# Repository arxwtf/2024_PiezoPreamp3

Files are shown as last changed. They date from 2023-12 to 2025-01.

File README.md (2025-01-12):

# Piezo Preamp with Baxandall Tone Control and Battery Indicator

A simple preamp to be used for e.g. guitar piezo (contact) microphones. 

Created in KiCAD v8 and LTSpice.

### [**User manual**](Arx_PiezoPreamp-User_Manual.pdf) | [**Detailed info**](https://arx.wtf/blog/3-piezo-preamp) | [**Enclosure**](https://github.com/arxwtf/2024_PiezoPreamp3_Enclosure)

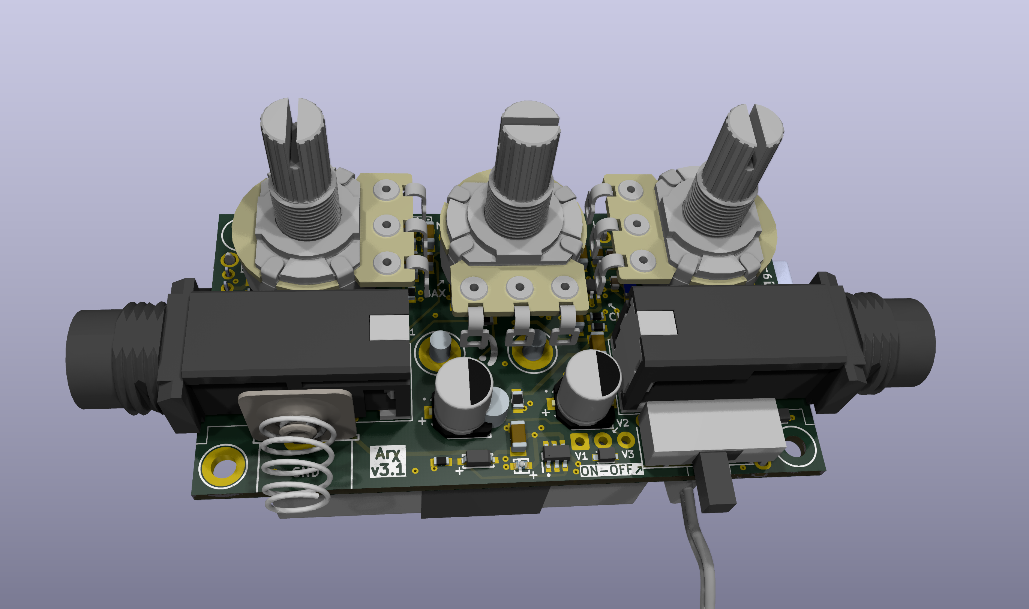
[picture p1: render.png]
Rendered PCB


## Main circuit blocks

### Charge amplifier for piezo 

Basically an integrator circuit. Provides low-impedance input. The gain is adjustable and depends on the input piezo capacitance. In my measurements, piezo discs have following capacitances:

- small disc (15mm diameter): ~7-10nF
- medium disc (27mm diameter): ~16-22nF
- large disc (35mm diameter): ~37-40nF

But I've also seen mentions of piezo discs with <10nF capacitance. Connecting multiple piezo discs in parallel increases the capacitance, so the maximum piezo capacitance can be in order of ~100nF or so.

The gain of the charge amp is then set by the ration of piezo capacitance to charge amp feedback capacitance. The **gain slide switch** is used to select from these feedback capacitances:

- 1nF
- 5.7nF
- 10.4nF
- 23nF

Input is protected by ESD bidirectional diode.

OPA145 is the opamp of choice because of these characteristics:
- JFET input stage, which means low input bias and offset current - critical for a charge amplifier
- low quiescent current (0.7mA max) for battery operation
- acceptable input voltage noise density (7nV/rtHz)
- good current noise density (0.8fA/rtHz)
- sufficient slew rate for audio (20V/us)
- sufficient GBW (5.5MHz)
- single supply voltage range 4.5V - 36V
- output voltage swing (V- +0.3, V+ -0.3)

Opamp also unfortunately seems to have bias current cancellation, which might introduce more current noise - this has to be determined by measurement. The same opamp is also used for Baxandall tone control section. Two single OPA145 components are used instead of dual OPA2145 package because it's easier to route, minimizes crosstalk and improves power dissipation (less heat). This increases the price, of course.

### High-pass filter with HPF switch

The charge amp is followed by a simple first-order high-pass filter with switchable cutoff frequency:
- 0Hz 
- 50Hz
- 77Hz
- 113Hz

The cutoff frequency is selectable by **HPF slide switch**.

### Baxandall tone control with Center switch

Bass and treble can be adjusted independently by **Bass pot** and **Treble pot** in the ranges of +-10dB. The center frequency is switchable by **Center slide switch**:

- 350Hz
- 600Hz
- 1kHz

Output audio is routed through **Volume pot** and protected by ESD bidirectional diode.

### Power-on LED and battery indicator
The power-on LED can work in two modes, switchable by LED mode switch:
- always on (switch left)
- "battery indication mode" (switch right)

**Battery indication mode (BI)** causes the LED to flash briefly when the circuit is switched on (by inserting mono plug to output jack + moving the power-on switch to the right). The longer the flash, the lower the battery voltage (remaining capacity). Under certain threshold, the LED will stay on permanentnly, signalling the need for replacement. This **BI threshold** is adjustable by on-board trimmer pot and needs to be determined by voltmeter measurement.

### Power supply
Designed for 9V batteries or DC pedal power supplies, but should theoretically be able to work properly with up to 18V DC.

Power enters the PCB by means of standardi 5.5/2.1mm DC IN connector with switch to disconnect internal 9V battery.

Contains ESD protection (bidirectional diode), MOSFET reverse polarity protection (with Zener gate protection and CLR) and input pi filter.

### OFF/ON switch with true bypass
The power-on switch works as a true bypass switch in its left position. The device is switched on by moving the switch to the right and insertin a **mono** male audio plug into the output jack.

## Simulation: /ltspice folder
LTSpice simulations (transient, AC, noise, stability) and some graphs are available in `ltspice/` folder.

## /library folder
Folder containing all 3rd symbols, footprints and 3D models used in the project. Other than that, only standard KiCAD symbols are used (opamps, ).

## /production folder
Contains gerbers, position files, BOM file, screenshot of JLC settings etc.

## /resources folder
Contains some additional resources, inspiration and schematics used during development.

## /schematics folder
Contains schematic sheets plotted from KiCAD, individually as .png and in one file as .pdf.

## Known problems
- when the circuit is turned ON or OFF (by the power-on switch and inserting of cable into AUDIO OUT jack), it might produce a strong voltage transient (a loud "pop"). Be careful when you're using it with sensitive equipment downstream.

- battery spring (used only for grounding) is too close to the PCB edge. This creates unnecessary force between the PCB and the enclosure wall. The spring can be shortened, or not used at all.

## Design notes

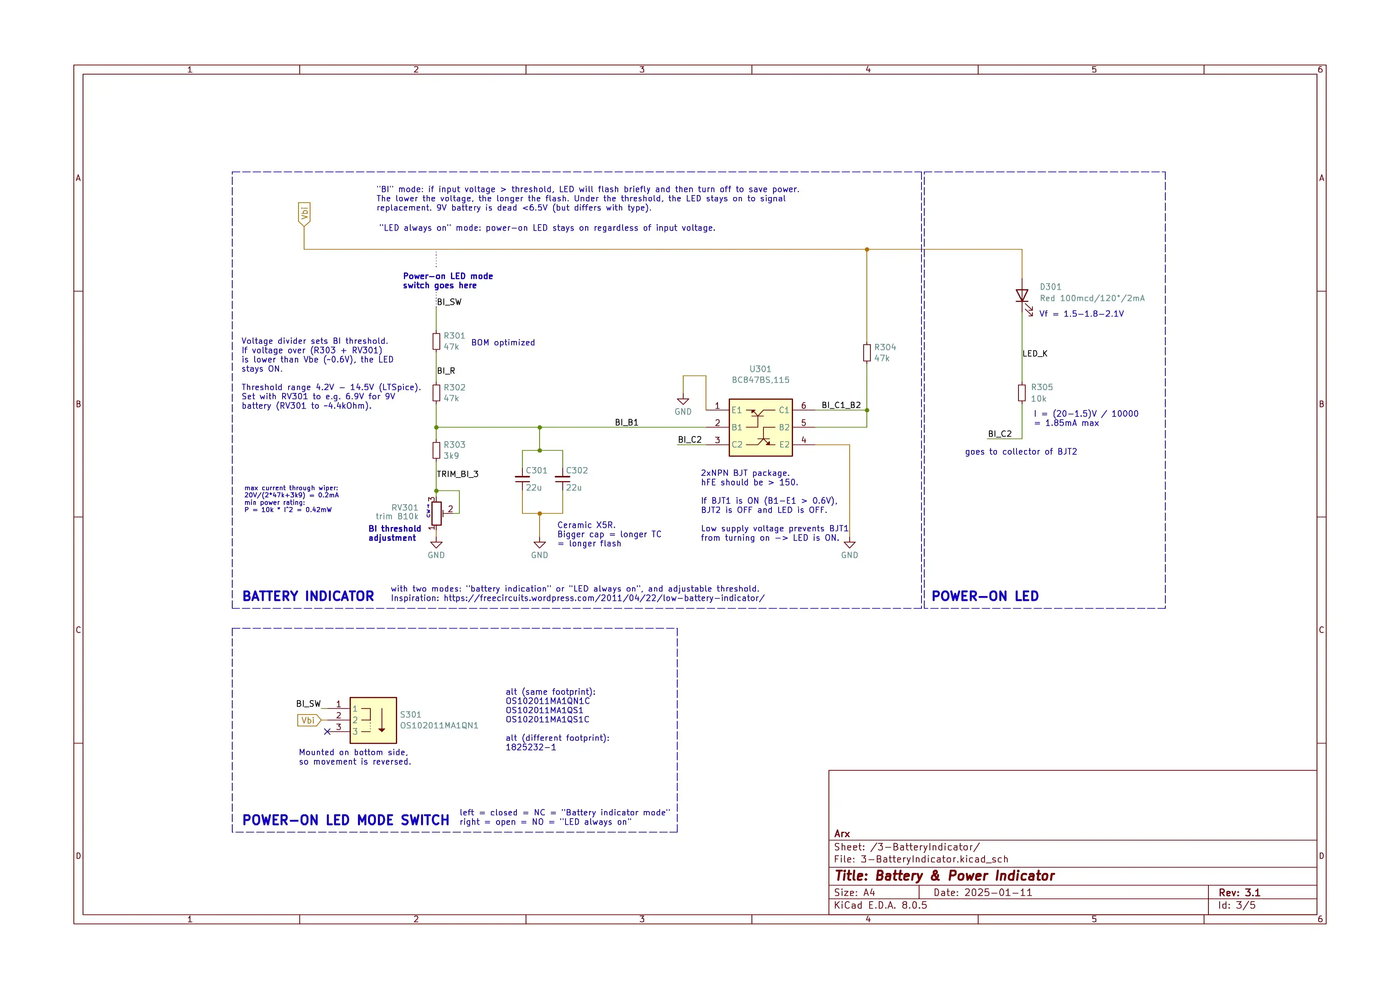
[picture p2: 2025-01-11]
schematics/3-BatteryIndicator.webp

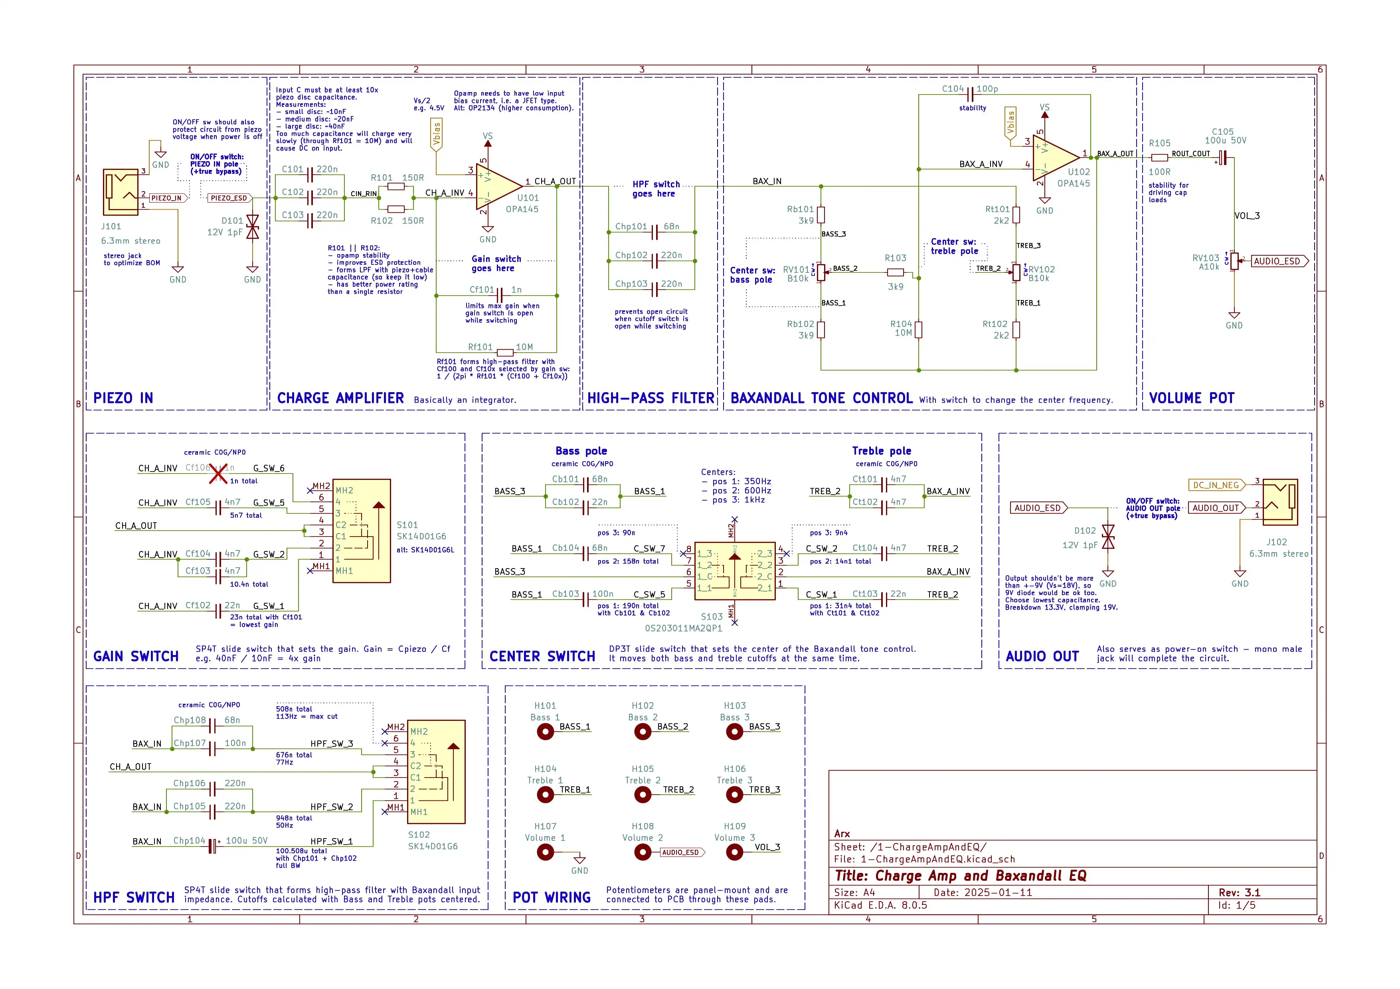
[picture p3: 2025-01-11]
schematics/1-ChargeAmpAndEQ.webp

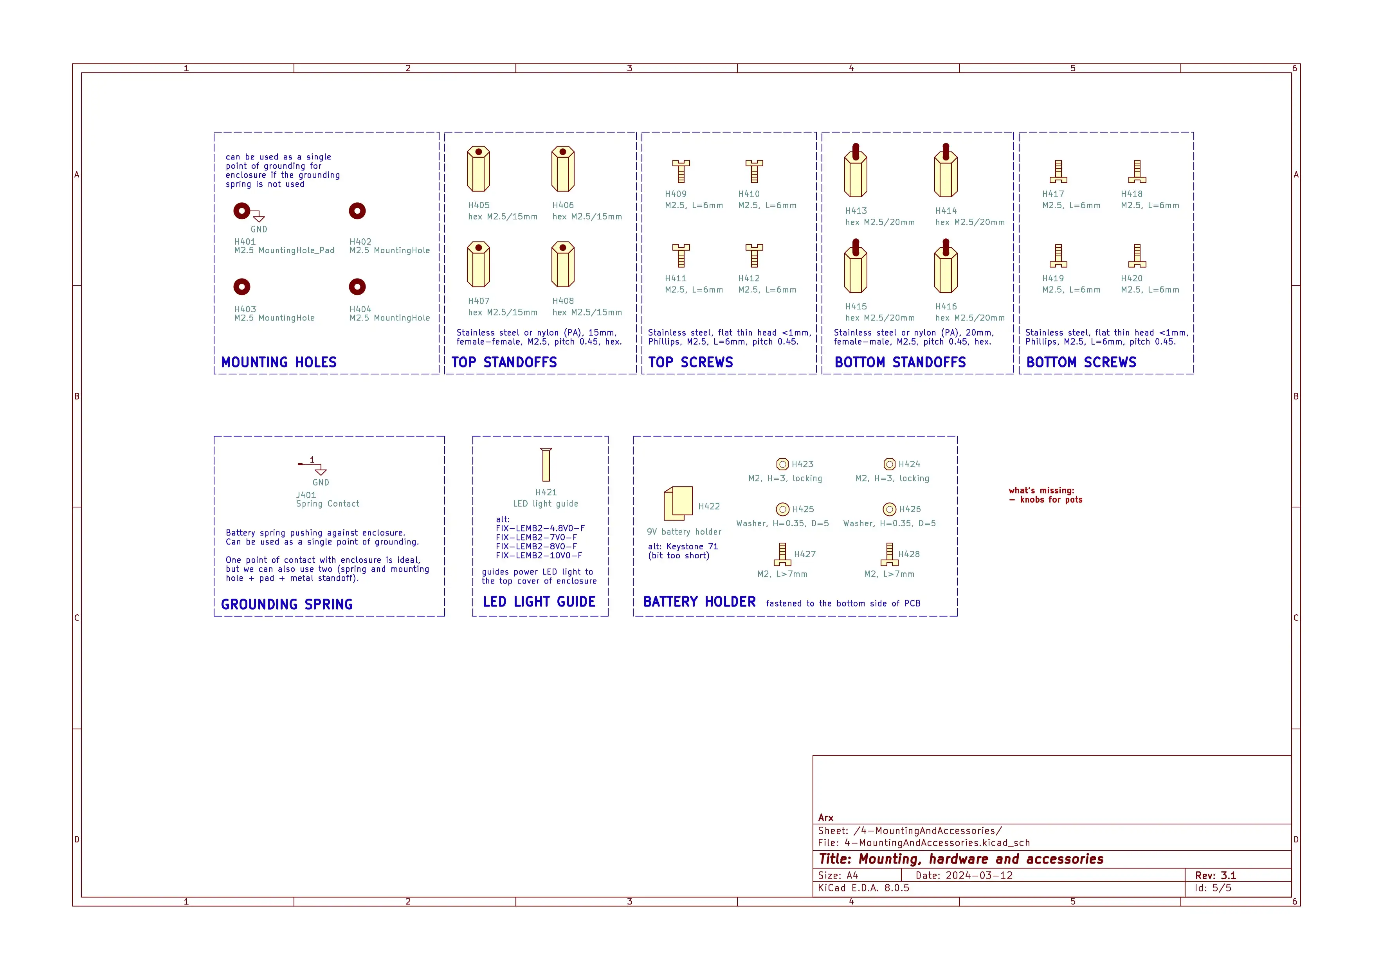
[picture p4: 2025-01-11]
schematics/4-MountingAndAccessories.webp

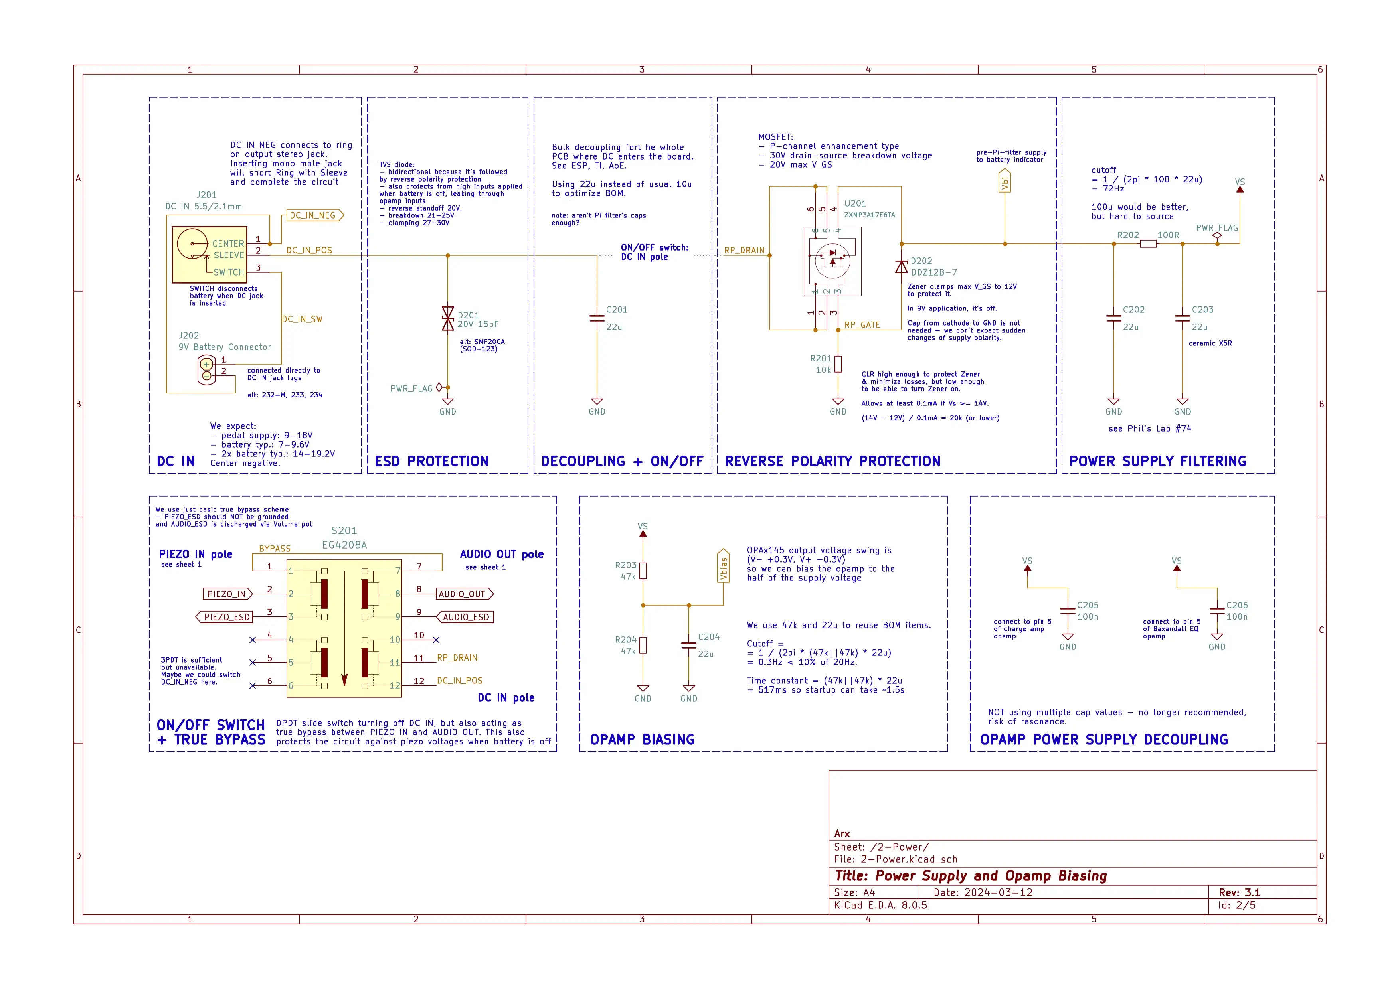
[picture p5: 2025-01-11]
schematics/2-Power.webp

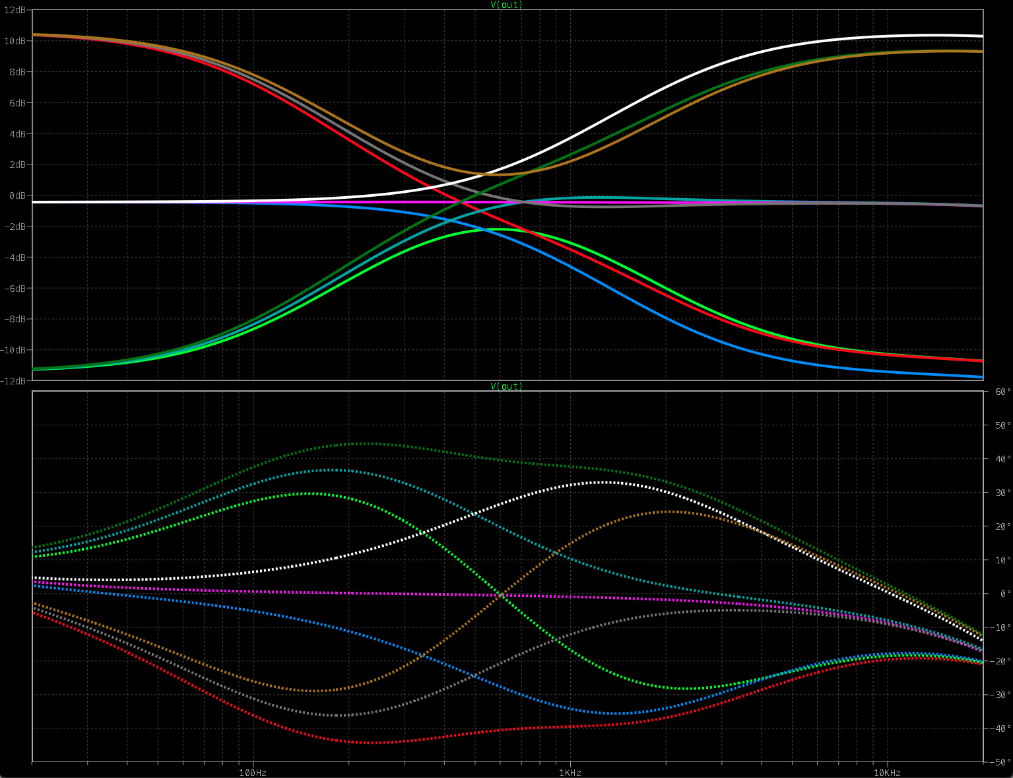
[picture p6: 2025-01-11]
ltspice/simulation-charge_amp+bax_600Hz.png

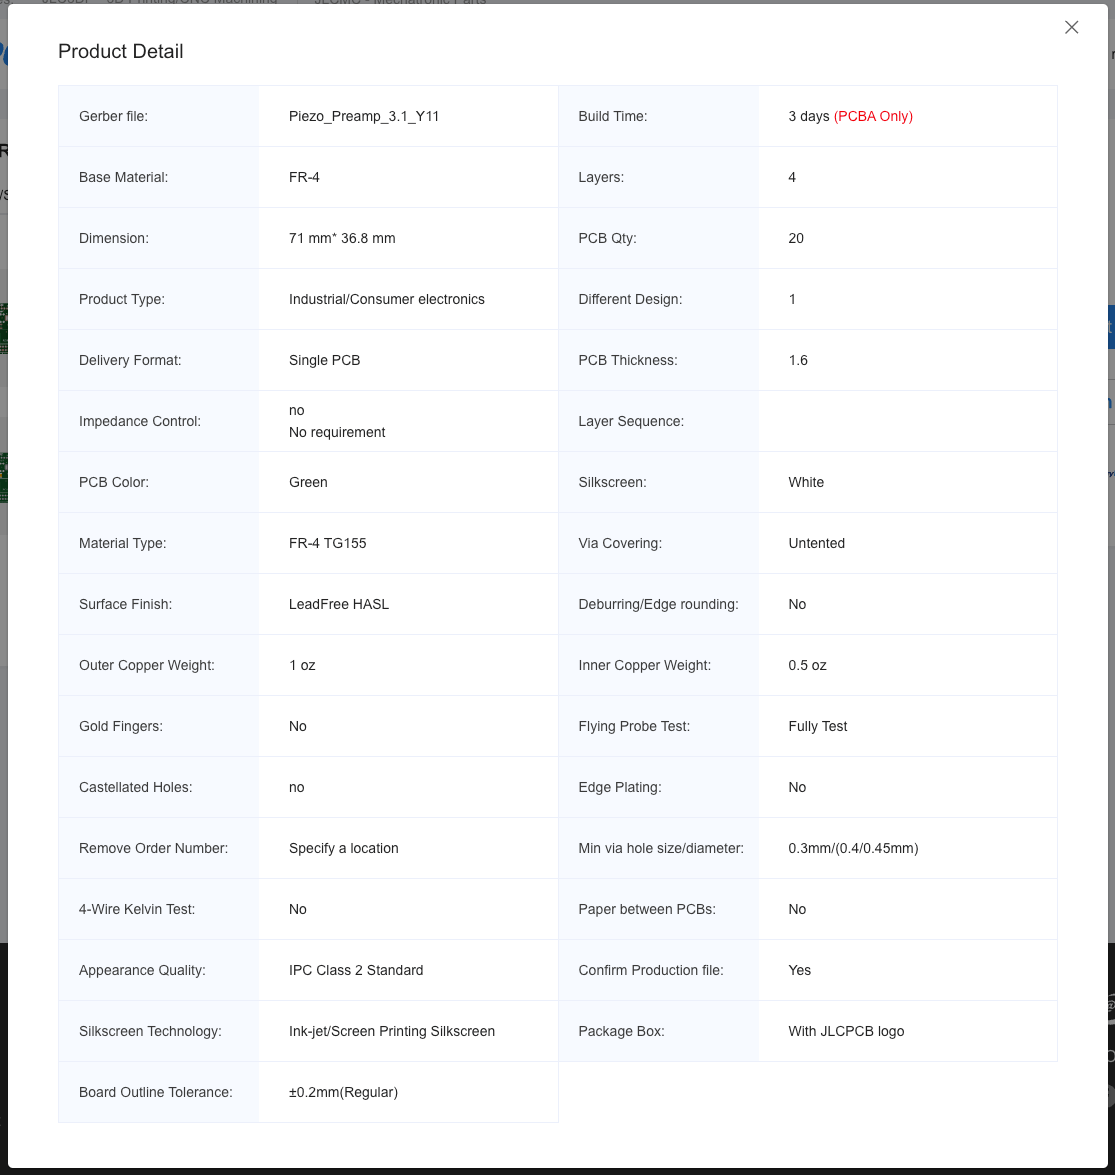
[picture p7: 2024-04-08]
production/settings/JLCPCB-Fab_settings_v3_1.png

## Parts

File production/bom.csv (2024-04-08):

Designator | Footprint | Quantity | Value | LCSC Part #
C101, C102, C103, Chp102, Chp103, Chp105, Chp106 | GRM31C5C1H224JE02L | 7 | 220n | C464977
C104 | cap_CL10C101JB8NNNC | 1 | 100p | C14858
C105, Chp104 | EEEFTH101XAP | 2 | 100u 50V | C165974
C201, C202, C203, C204, C301, C302 | cap_CL31A226KAHNNNE | 6 | 22u | C12891
C205, C206, Cb103, Chp107 | GRM31C5C1H104JA01L | 4 | 100n | C97946
Cb101, Cb104, Chp101, Chp108 | GRM31C5C1H683JA01L | 4 | 68n | C77084
Cb102, Cf102, Ct103 | GRM21B5C1H223JA01L | 3 | 22n | C77069
Cf101 | GRM1885C1H102JA01D | 1 | 1n | C77026
Cf103, Cf104, Cf105, Ct101, Ct102, Ct104 | GRM1885C1H472JA01D | 6 | 4n7 | C85980
D101, D102 | CDSOD323-T12LC | 2 | 12V 1pF | C911368
D201 | D20V0L1B2WS-7 | 1 | 20V 15pF | C507921
D202 | DDZ12B-7 | 1 | DDZ12B-7 | C2760568
D301 | APT1608LSECK_J3-PRV | 1 | Red 100mcd/120°/2mA | C5357909
H422 | KEYSTONE-71 | 1 | 9V battery holder | -
J101, J102 | CUI_SJ-63053A | 2 | 6.3mm stereo | -
J201 | 694106301002 | 1 | DC IN 5.5/2.1mm | -
J401 | KEYSTONE-5201 | 1 | Spring Contact | -
R101, R102 | ERA-3AEB151V | 2 | 150R | C543626
R103, R303, Rb101, Rb102 | RT0603FRE073K9L | 4 | 3k9 | C863790
R104, Rf101 | MCA1206MD1005BP100 | 2 | 10M | C4259100
R105, R202 | ERA-6AEB101V | 2 | 100R | C445646
R201, R305 | RT0603BRD0710KL | 2 | 10k | C95204
R203, R204, R301, R302, R304 | RT0603FRD0747KL | 5 | 47k | C728633
RV301 | trimpot_TC33X-2-103E | 1 | trim B10k | C719176
Rt101, Rt102 | RT0603DRD072K2L | 2 | 2k2 | C705970
S101, S102 | sw_SK14D01G6 | 2 | SK14D01G6
S103 | sw_0S203011MA2QP1 | 1 | 0S203011MA2QP1
S201 | EG4208A | 1 | EG4208A | -
S301 | OS102011MA1QN1 | 1 | OS102011MA1QN1 | -
U101, U102 | OPA145IDBVR | 2 | OPA145 | C2058624
U201 | ZXMP3A17E6TA | 1 | ZXMP3A17E6TA | C154715
U301 | bjt_BC847BS_115 | 1 | BC847BS,115 | C8653

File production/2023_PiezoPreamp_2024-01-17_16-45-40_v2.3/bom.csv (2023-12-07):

Designator | Footprint | Quantity | Value | LCSC Part #
C101, Clp103 | EEEFK1H100UR | 2 | 10u 50V | C178547
C102 | GRM1885C1H101JA01D | 1 | 100p | C71664
C103 | EEEFTH101XAP | 1 | 100u 50V | C165974
C201, C202, C301 | GRM21BR61E226ME44L | 3 | 22u | C86816
C203, C205, C207 | C3216X5R1H106K160AB | 3 | 10u | C329928
C204, C206, Cb102 | GRM31C5C2A104JA01L | 3 | 100n | C405303
Cb101, Cb103, Clp101 | GRM31C5C1H683JA01L | 3 | 68n | C77084
Cb104, Cf102, Ct102 | CGA4J2C0G1H223J125AA | 3 | 22n | C415303
Cf101 | GRM1885C1H102JA01D | 1 | 1n | C77026
Cf103 | GRM1885C1H103JA01D | 1 | 10n | C85973
Cf104, Ct104 | GRM1885C1H472JA01D | 2 | 4n7 | C85980
Clp102, Clp104, Clp105, Clp106 | GRM31C5C1H224JE02L | 4 | 220n | C464977
Ct101, Ct103 | GRM1885C1H682JA01D | 2 | 6n8 | C162241
D101, D102 | CDSOD323-T12LC | 2 | 12V 1pF | C911368
D201 | D20V0L1B2WS-7 | 1 | 20V 15pF | C507921
D202 | DDZ12B-7 | 1 | DDZ12B-7 | C2760568
D301 | APT1608LSECK_J3-PRV | 1 | Red 100mcd/120°/2mA | C5357909
R101, R102 | RT0603BRD07150RL_UL-M | 2 | 150R | C705726
R103, R302, R304, Rb101, Rb102 | ERA-3AEB392V | 5 | 3k9 | C473237
R104, Rf101 | MCA1206MD1005BP100 | 2 | 10M | C4259100
R105, R202 | ERA-6AEB101V | 2 | 100R | C445646
R201 | RT0603BRD0710KL | 1 | 10k | C95204
R203, R204, R303 | RT0603BRD0747KL | 3 | 47k | C326725
R301 | RT0603BRD07100KL | 1 | 100k | C122538
RV301, RV302 | ST-4ETB103 | 2 | trim B10k | C2922095
Rt101, Rt102 | RT0603DRD072K2L | 2 | 2k2 | C705970
U101, U102 | OPA145IDBVR | 2 | OPA145 | C2058624
U201 | ZXMP3A17E6TA | 1 | ZXMP3A17E6TA | C154715
U301 | MMDT2222A-7-F | 1 | MMDT2222A-7-F | C96379

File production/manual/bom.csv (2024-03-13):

# | Reference | Qty | Value | Footprint | Mfr Part # | LCSC Part #
1 | C101 | 1 | 220n | library:GRM31C5C1H224JE02L | GRM31C5C1H224JE02L | C464977
2 | C102 | 1 | 220n | library:GRM31C5C1H224JE02L | GRM31C5C1H224JE02L | C464977
3 | C103 | 1 | 220n | library:GRM31C5C1H224JE02L | GRM31C5C1H224JE02L | C464977
4 | C104 | 1 | 100p | library:cap_CL10C101JB8NNNC | CL10C101JB8NNNC | C14858
5 | C105 | 1 | 100u 50V | library:EEEFTH101XAP | EEEFTH101XAP | C165974
6 | C201 | 1 | 22u | library:cap_CL31A226KAHNNNE | CL31A226KAHNNNE | C12891
7 | C202 | 1 | 22u | library:cap_CL31A226KAHNNNE | CL31A226KAHNNNE | C12891
8 | C203 | 1 | 22u | library:cap_CL31A226KAHNNNE | CL31A226KAHNNNE | C12891
9 | C204 | 1 | 22u | library:cap_CL31A226KAHNNNE | CL31A226KAHNNNE | C12891
10 | C205 | 1 | 100n | library:GRM31C5C1H104JA01L | GRM31C5C1H104JA01L | C97946
11 | C206 | 1 | 100n | library:GRM31C5C1H104JA01L | GRM31C5C1H104JA01L | C97946
12 | C301 | 1 | 22u | library:cap_CL31A226KAHNNNE | CL31A226KAHNNNE | C12891
13 | C302 | 1 | 22u | library:cap_CL31A226KAHNNNE | CL31A226KAHNNNE | C12891
14 | Cb101 | 1 | 68n | library:GRM31C5C1H683JA01L | GRM31C5C1H683JA01L | C77084
15 | Cb102 | 1 | 22n | library:GRM21B5C1H223JA01L | GRM21B5C1H223JA01L | C77069
16 | Cb103 | 1 | 100n | library:GRM31C5C1H104JA01L | GRM31C5C1H104JA01L | C97946
17 | Cb104 | 1 | 68n | library:GRM31C5C1H683JA01L | GRM31C5C1H683JA01L | C77084
18 | Cf101 | 1 | 1n | library:GRM1885C1H102JA01D | GRM1885C1H102JA01D | C77026
19 | Cf102 | 1 | 22n | library:GRM21B5C1H223JA01L | GRM21B5C1H223JA01L | C77069
20 | Cf103 | 1 | 4n7 | library:GRM1885C1H472JA01D | GRM1885C1H472JA01D | C85980
21 | Cf104 | 1 | 4n7 | library:GRM1885C1H472JA01D | GRM1885C1H472JA01D | C85980
22 | Cf105 | 1 | 4n7 | library:GRM1885C1H472JA01D | GRM1885C1H472JA01D | C85980
23 | Chp101 | 1 | 68n | library:GRM31C5C1H683JA01L | GRM31C5C1H683JA01L | C77084
24 | Chp102 | 1 | 220n | library:GRM31C5C1H224JE02L | GRM31C5C1H224JE02L | C464977
25 | Chp103 | 1 | 220n | library:GRM31C5C1H224JE02L | GRM31C5C1H224JE02L | C464977
26 | Chp104 | 1 | 100u 50V | library:EEEFTH101XAP | EEEFTH101XAP | C165974
27 | Chp105 | 1 | 220n | library:GRM31C5C1H224JE02L | GRM31C5C1H224JE02L | C464977
28 | Chp106 | 1 | 220n | library:GRM31C5C1H224JE02L | GRM31C5C1H224JE02L | C464977
29 | Chp107 | 1 | 100n | library:GRM31C5C1H104JA01L | GRM31C5C1H104JA01L | C97946
30 | Chp108 | 1 | 68n | library:GRM31C5C1H683JA01L | GRM31C5C1H683JA01L | C77084
31 | Ct101 | 1 | 4n7 | library:GRM1885C1H472JA01D | GRM1885C1H472JA01D | C85980
32 | Ct102 | 1 | 4n7 | library:GRM1885C1H472JA01D | GRM1885C1H472JA01D | C85980
33 | Ct103 | 1 | 22n | library:GRM21B5C1H223JA01L | GRM21B5C1H223JA01L | C77069
34 | Ct104 | 1 | 4n7 | library:GRM1885C1H472JA01D | GRM1885C1H472JA01D | C85980
35 | D101 | 1 | 12V 1pF | library:CDSOD323-T12LC | CDSOD323-T12LC | C911368
36 | D102 | 1 | 12V 1pF | library:CDSOD323-T12LC | CDSOD323-T12LC | C911368
37 | D201 | 1 | 20V 15pF | library:D20V0L1B2WS-7 | D20V0L1B2WS-7 | C507921
38 | D202 | 1 | DDZ12B-7 | library:DDZ12B-7 | DDZ12B-7 | C2760568
39 | D301 | 1 | Red 100mcd/120°/2mA | library:APT1608LSECK_J3-PRV | APT1608LSECK/J3-PRV | C5357909
40 | H405 | 1 | hex M2.5/15mm |  | 1212X15 | -
41 | H406 | 1 | hex M2.5/15mm |  | 1212X15 | -
42 | H407 | 1 | hex M2.5/15mm |  | 1212X15 | -
43 | H408 | 1 | hex M2.5/15mm |  | 1212X15 | -
44 | H409 | 1 | M2.5, L=6mm |  | - | -
45 | H410 | 1 | M2.5, L=6mm |  | - | -
46 | H411 | 1 | M2.5, L=6mm |  | - | -
47 | H412 | 1 | M2.5, L=6mm |  | - | -
48 | H413 | 1 | hex M2.5/20mm |  | 2212X20 | -
49 | H414 | 1 | hex M2.5/20mm |  | 2212X20 | -
50 | H415 | 1 | hex M2.5/20mm |  | 2212X20 | -
51 | H416 | 1 | hex M2.5/20mm |  | 2212X20 | -
52 | H417 | 1 | M2.5, L=6mm |  | - | -
53 | H418 | 1 | M2.5, L=6mm |  | - | -
54 | H419 | 1 | M2.5, L=6mm |  | - | -
55 | H420 | 1 | M2.5, L=6mm |  | - | -
56 | H421 | 1 | LED light guide |  | FIX-LEMB2-10V0-F | -
57 | H422 | 1 | 9V battery holder | library:KEYSTONE-71 | 79 | -
58 | H423 | 1 | M2, H=3, locking |  | - | -
59 | H424 | 1 | M2, H=3, locking
60 | H425 | 1 | Washer, H=0.35, D=5 |  | - | -
61 | H426 | 1 | Washer, H=0.35, D=5 |  | - | -
62 | H427 | 1 | M2, L>7mm |  | - | -
63 | H428 | 1 | M2, L>7mm |  | - | -
64 | J101 | 1 | 6.3mm stereo | library:CUI_SJ-63053A | SJ-63053A | -
65 | J102 | 1 | 6.3mm stereo | library:CUI_SJ-63053A | SJ-63053A | -
66 | J201 | 1 | DC IN 5.5/2.1mm | library:694106301002 | 694106301002 | -
67 | J202 | 1 | 9V Battery Connector |  | 232 | -
68 | J401 | 1 | Spring Contact | library:KEYSTONE-5201 | 5201 | -
69 | R101 | 1 | 150R | library:ERA-3AEB151V | ERA3AEB151V | C543626
70 | R102 | 1 | 150R | library:ERA-3AEB151V | ERA3AEB151V | C543626
71 | R103 | 1 | 3k9 | library:RT0603FRE073K9L | RT0603FRE073K9L | C863790
72 | R104 | 1 | 10M | library:MCA1206MD1005BP100 | MCA1206MD1005BP100 | C4259100
73 | R105 | 1 | 100R | library:ERA-6AEB101V | ERA-6AEB101V | C445646
74 | R201 | 1 | 10k | library:RT0603BRD0710KL | RT0603BRD0710KL | C95204
75 | R202 | 1 | 100R | library:ERA-6AEB101V | ERA-6AEB101V | C445646
76 | R203 | 1 | 47k | library:RT0603FRD0747KL | RT0603FRD0747KL | C728633
77 | R204 | 1 | 47k | library:RT0603FRD0747KL | RT0603FRD0747KL | C728633
78 | R301 | 1 | 47k | library:RT0603FRD0747KL | RT0603FRD0747KL | C728633
79 | R302 | 1 | 47k | library:RT0603FRD0747KL | RT0603FRD0747KL | C728633
80 | R303 | 1 | 3k9 | library:RT0603FRE073K9L | RT0603FRE073K9L | C863790
81 | R304 | 1 | 47k | library:RT0603FRD0747KL | RT0603FRD0747KL | C728633
82 | R305 | 1 | 10k | library:RT0603BRD0710KL | RT0603BRD0710KL | C95204
83 | Rb101 | 1 | 3k9 | library:RT0603FRE073K9L | RT0603FRE073K9L | C863790
84 | Rb102 | 1 | 3k9 | library:RT0603FRE073K9L | RT0603FRE073K9L | C863790
85 | Rf101 | 1 | 10M | library:MCA1206MD1005BP100 | MCA1206MD1005BP100 | C4259100
86 | Rt101 | 1 | 2k2 | library:RT0603DRD072K2L | RT0603DRD072K2L | C705970
87 | Rt102 | 1 | 2k2 | library:RT0603DRD072K2L | RT0603DRD072K2L | C705970
88 | RV101 | 1 | B10k |  | R16148-1A-1-B10K | -
89 | RV102 | 1 | B10k |  | R16148-1A-1-B10K | -
90 | RV103 | 1 | A10k |  | R16148-1A-1-A10K | -
91 | RV301 | 1 | trim B10k | library:trimpot_TC33X-2-103E | TC33X-2-103E | C719176
92 | S101 | 1 | SK14D01G6 | library:sw_SK14D01G6 | SK14D01G6
93 | S102 | 1 | SK14D01G6 | library:sw_SK14D01G6 | SK14D01G6
94 | S103 | 1 | 0S203011MA2QP1 | library:sw_0S203011MA2QP1 | 0S203011MA2QP1
95 | S201 | 1 | EG4208A | library:EG4208A | EG4208A | -
96 | S301 | 1 | OS102011MA1QN1 | library:OS102011MA1QN1 | OS102011MA1QN1 | -
97 | U101 | 1 | OPA145 | library:OPA145IDBVR | OPA145IDBVR | C2058624
98 | U102 | 1 | OPA145 | library:OPA145IDBVR | OPA145IDBVR | C2058624
99 | U201 | 1 | ZXMP3A17E6TA | library:ZXMP3A17E6TA | ZXMP3A17E6TA | C154715
100 | U301 | 1 | BC847BS,115 | library:bjt_BC847BS_115 | BC847BS,115 | C8653

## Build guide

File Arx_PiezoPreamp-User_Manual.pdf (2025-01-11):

manual version: 3.1.0, 09/2024

# Arx Piezo Preamp v3

# User Manual

You are looking at a preamplifier designed specifically for contact (piezo) microphones and pickups, typically used with acoustic instruments. Using contact microphones without a specialized preamp can result in suboptimal sound quality, particularly lacking in bass. The Arx Piezo Preamp utilizes a technology known as "charge amplifier," which features low input impedance, offering lower noise compared to traditional high-impedance piezo preamps.

The input preamp stage strives to be as transparent, as "flat" as possible, preserving the original microphone output without alteration in the full audio frequency range of 20Hz to 20kHz. The pure sound of the microphone therefore depends on the quality of your microphone, its position on the body of the instrument, and the method of attachment to the body. It often requires a bit of experimentation.

The preamp stage with Gain switch is followed by a High-Pass Filter stage, then Baxandall Bass / Treble tone control stage for fine-tuning, and lastly the Volume knob. The preamp can thus be used for many different types of acoustic instruments.

I created this preamp as a way to learn audio PCB design. It is produced in a DIY way in small batches in the EU. Thank you for choosing it!
-- Arx
arx.wtf

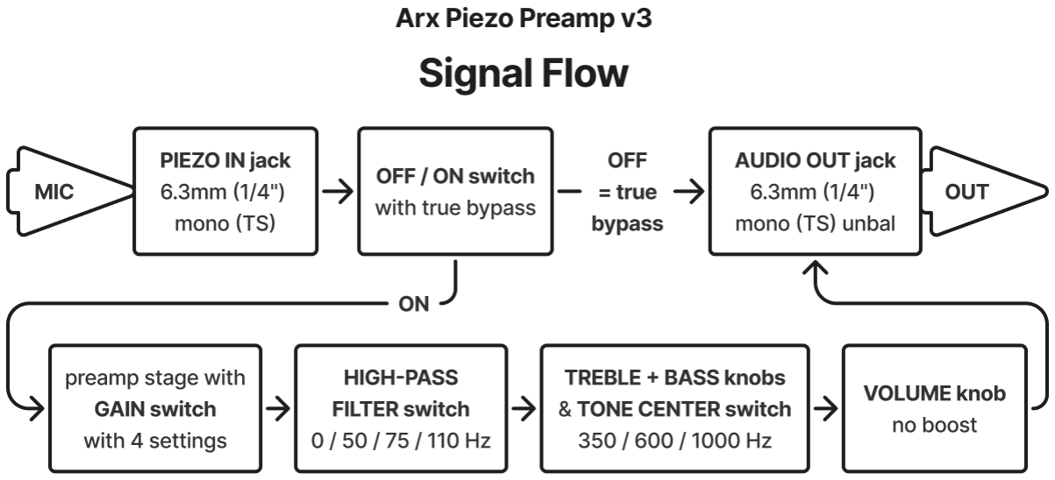
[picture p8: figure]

### Mounting the preamp

It is best to position the preamp as close to the piezo microphone / pickup as possible. Do not insert any other devices between the microphone and the preamp. The bottom side of the enclosure features protruding flanges with mounting holes. Use classic cable ties or velcro cable ties to mount the device to your instrument strap, utilizing these holes. Alternatively, mount the device on your pedalboard. The low-impedance input design should allow for a greater distance between the microphone and the preamp.

### Using a 9V battery

This device can be powered by a standard rectangular 9V "pedal" battery (aka PP3). Unscrew the bottom plate of the enclosure, attach the battery to the internal connector, insert the battery into the battery holder, and screw the bottom enclosure plate back on.

### 9V IN jack

Use 5.5/2.1mm DC plug, center-negative ("standard pedal"). Current draw is <10mA (typically 2mA). Features MOSFET reverse polarity protection. When you insert the plug into the jack, it also cuts off the battery. Word of caution: such switches are known to fail from time to time, so if you plan to power the device using a 9V IN jack, consider removing the battery.

### PIEZO IN jack

Mono 6.3mm (1/4") input jack for contact (piezo) microphones and pickups. Charge amplifier allows for the use of a low impedance input, improving noise immunity.

### AUDIO OUT jack

Mono 6.3mm (1/4") unbalanced output audio jack. Low impedance. A mono cable (TS) must be inserted so the device can be switched ON. Do not use stereo cables (TRS) - the device will not turn on.

### OFF/ON switch with true bypass

Switches the device between true bypass (OFF) and ON. The device also requires a 6.3mm (1/4") mono cable to be inserted into the AUDIO OUT jack to power on, preventing unnecessary battery drain if you forget to switch the device off.

### LED MODE switch

- Left position: The main power-on LED ("eye of the frog") will remain on while the device is on.
- Right position: The LED will be in battery indicator mode. It will flash briefly when the device is turned on, then turn off to conserve battery. When the battery voltage drops below 7V, the LED will stay on to indicate the need to replace the battery.

### GAIN switch

Sets the gain of the input preamp stage. The actual amount of gain depends on the capacitance of your piezo microphone(s) / pickup(s), which varies greatly between the microphones in the real world, therefore it is not possible to determine the gain exactly. Find the switch position that serves you best.

### HIGH-PASS FILTER switch

Applies a gentle 6dB/oct high-pass filter at 0Hz (no filtering) - 50Hz - 75Hz - 110Hz. This can be useful to suppress various unwanted thuds caused by handling of the instrument. This stage comes after the preamplifier stage, and before the tone control stage.

### BASS and TREBLE control

These cut or boost the bass and treble in the range of -10dB to +10dB. Classic Baxandall tone control. The center frequency (between BASS and TREBLE controls) is selectable by the TONE CENTER switch, changing filter cutoffs.

### TONE CENTER switch

Switches the center frequency (350Hz - 600Hz - 1000Hz) between BASS and TREBLE controls to allow for greater adaptability of the device to various instruments. For example, when the switch is on 350Hz, the BASS control will operate on frequencies below 350Hz and TREBLE control on frequencies above 350Hz.

### VOLUME control

Sets the final output audio volume of the device, after all the stages. No boost.

## Have fun!

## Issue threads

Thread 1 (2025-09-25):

Can this be powered with 5V?

jmrhvl, 2025-09-25:
I am working on a project which uses piezo mics and will be powered by a 5V input.

Will this preamp be able to work at 5V? It says something like that about the OPA145, but how about the whole circuit?

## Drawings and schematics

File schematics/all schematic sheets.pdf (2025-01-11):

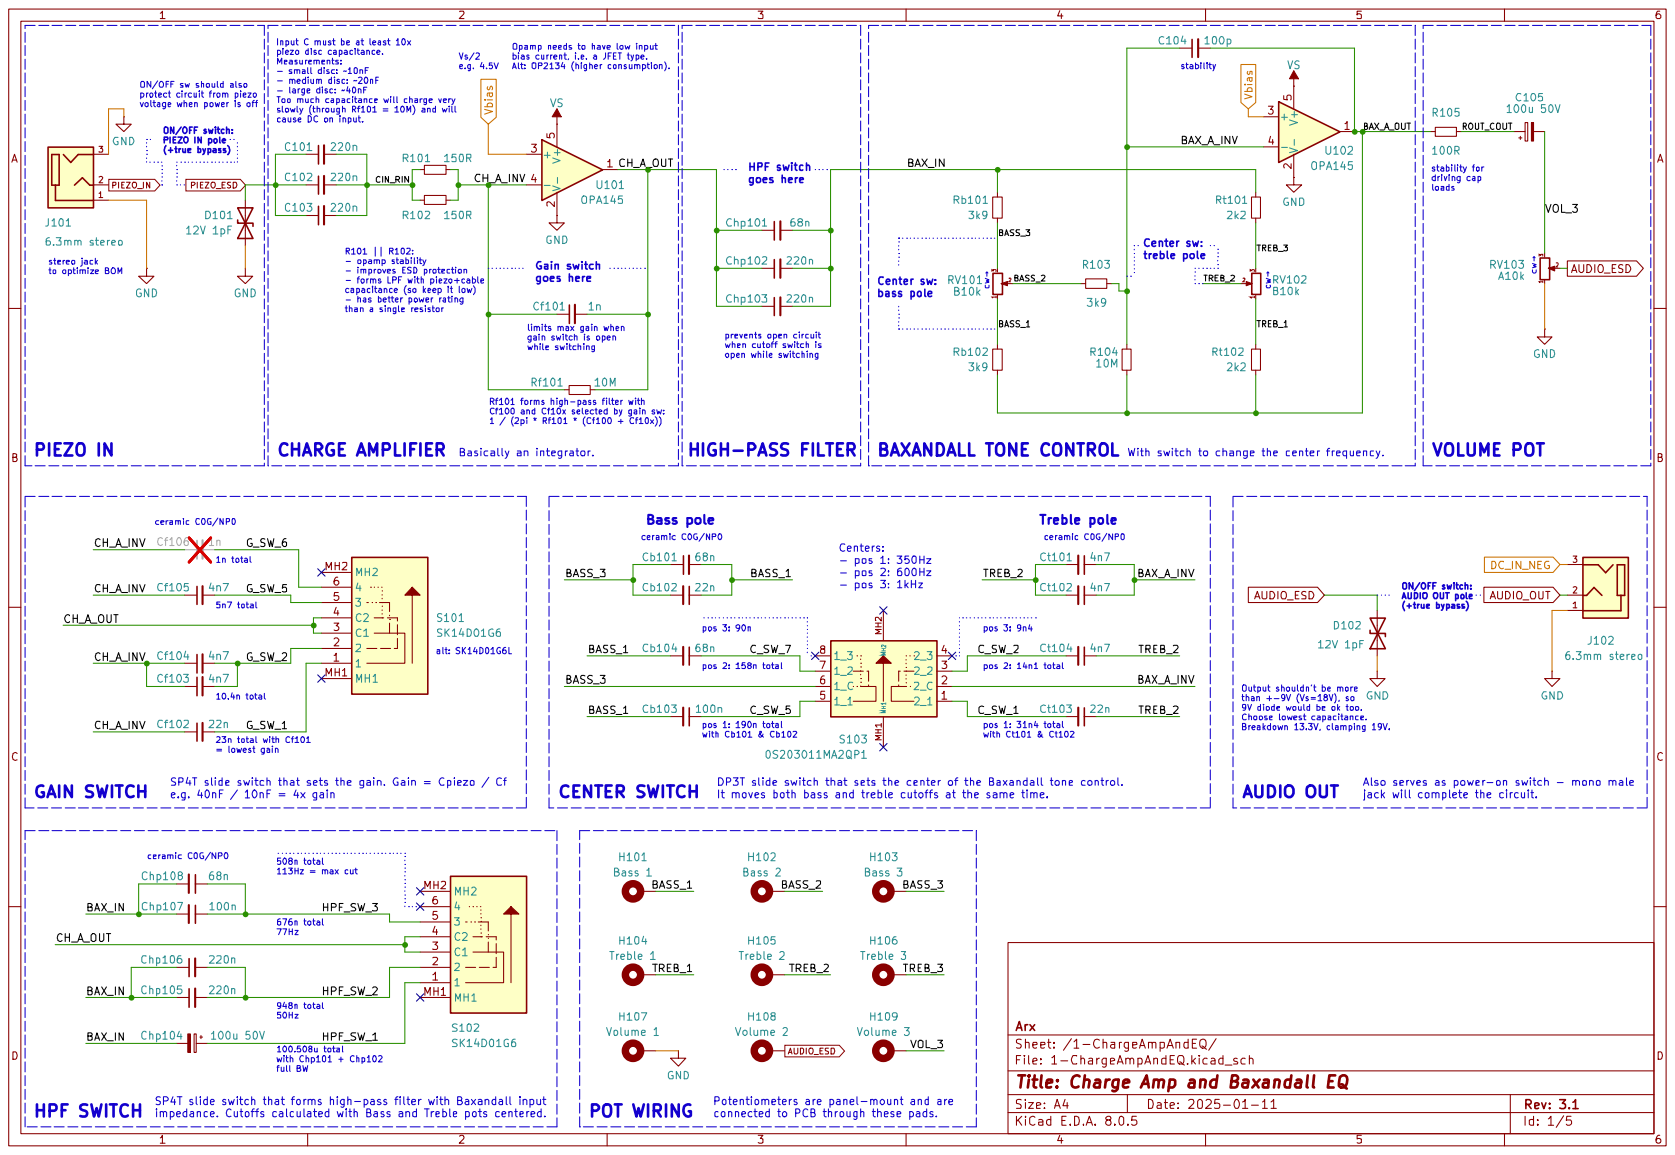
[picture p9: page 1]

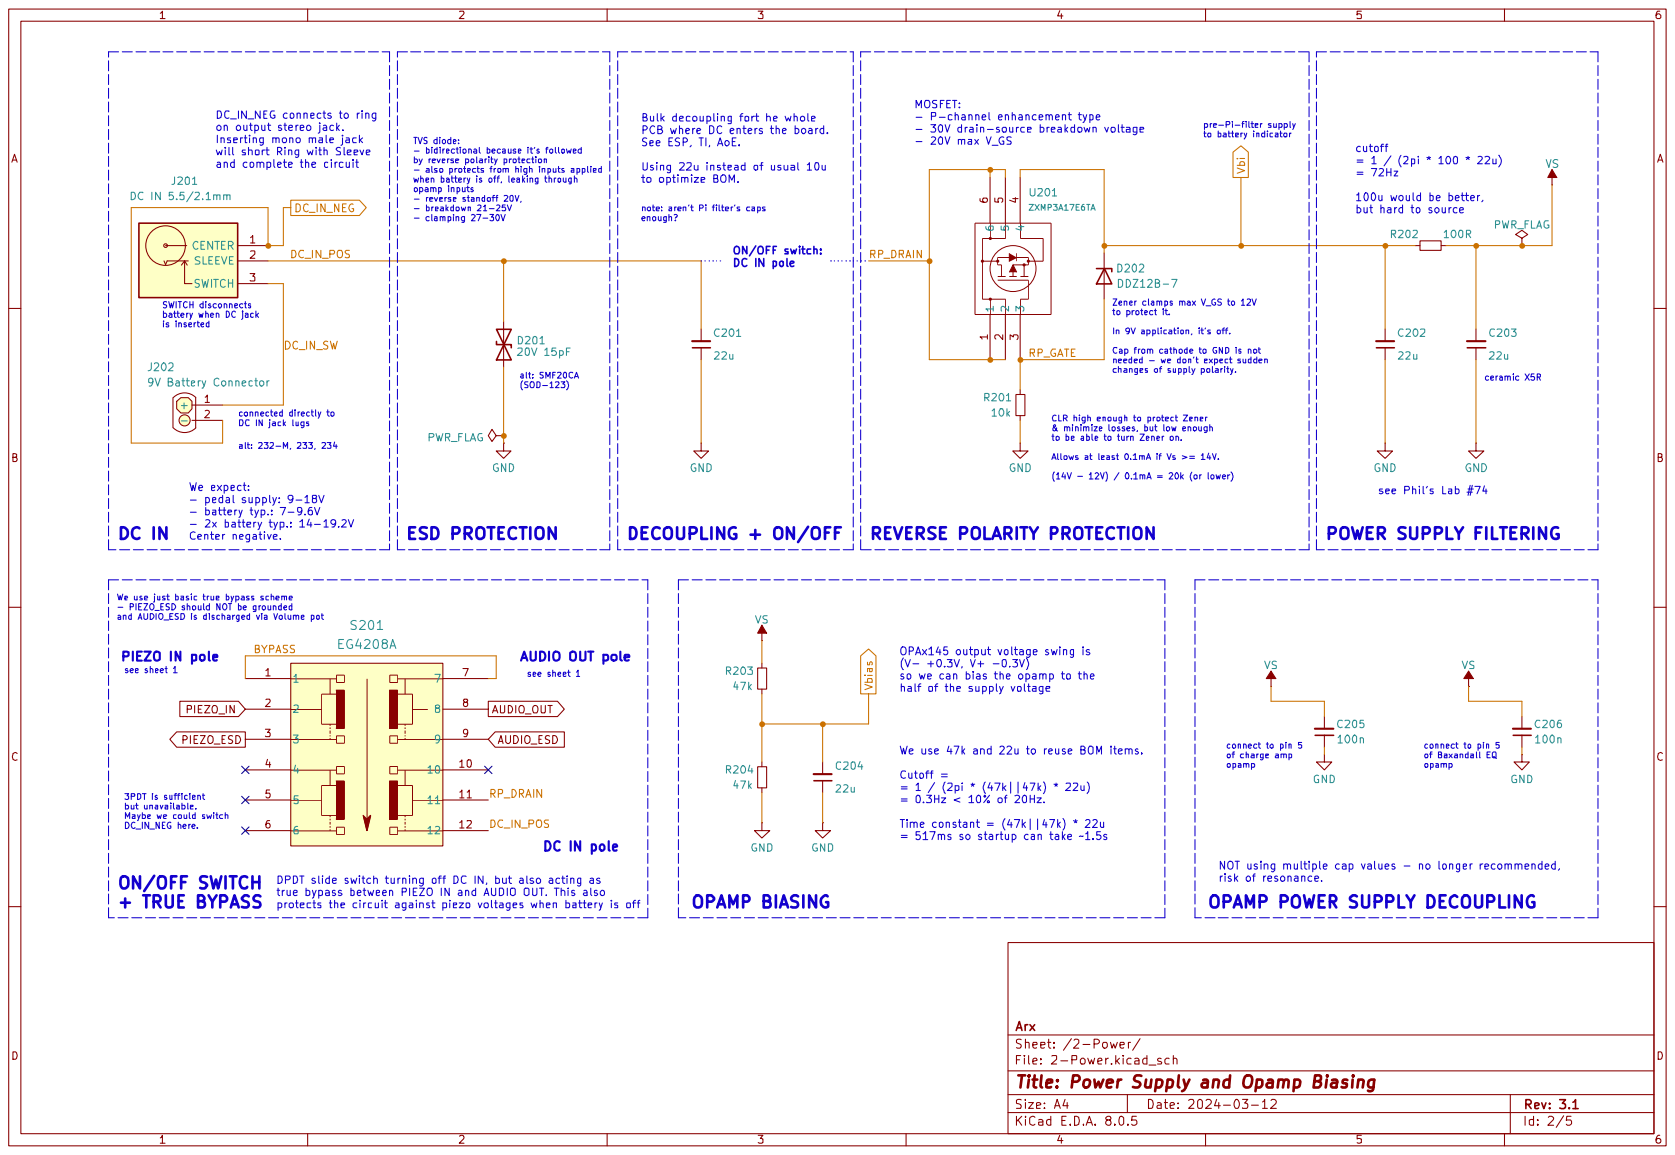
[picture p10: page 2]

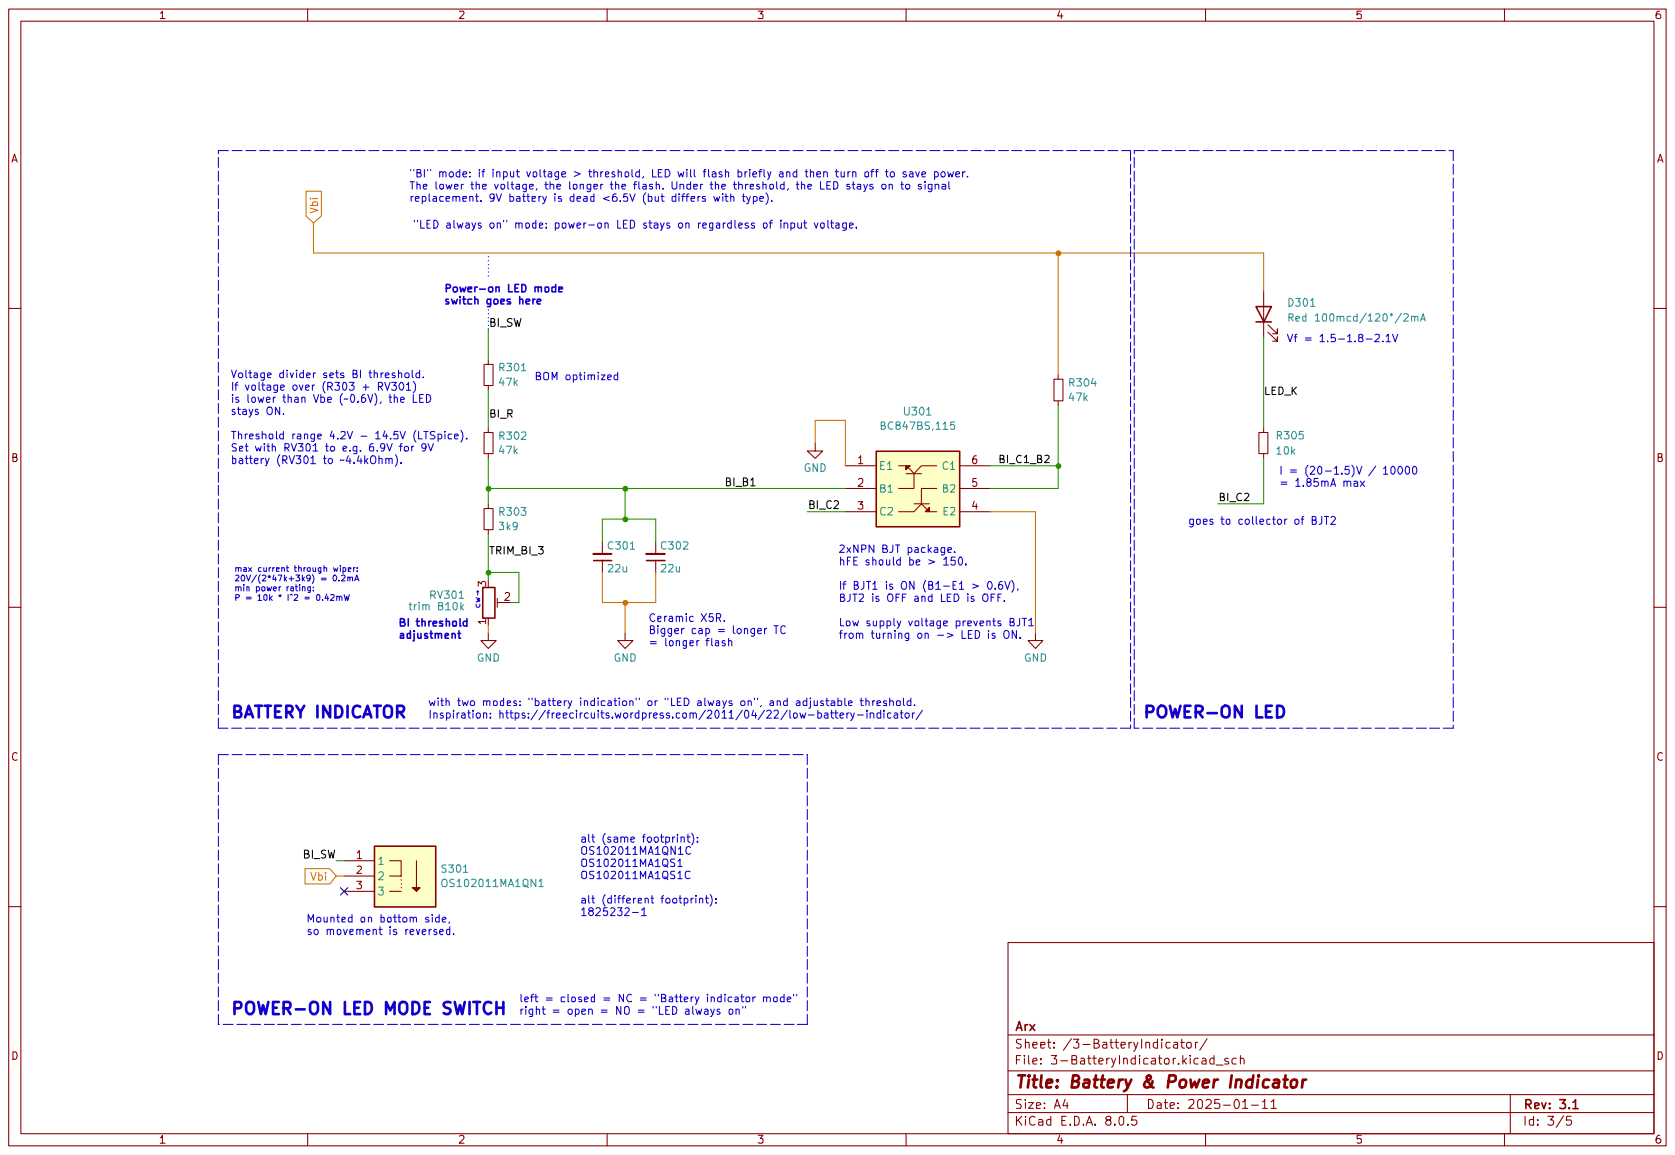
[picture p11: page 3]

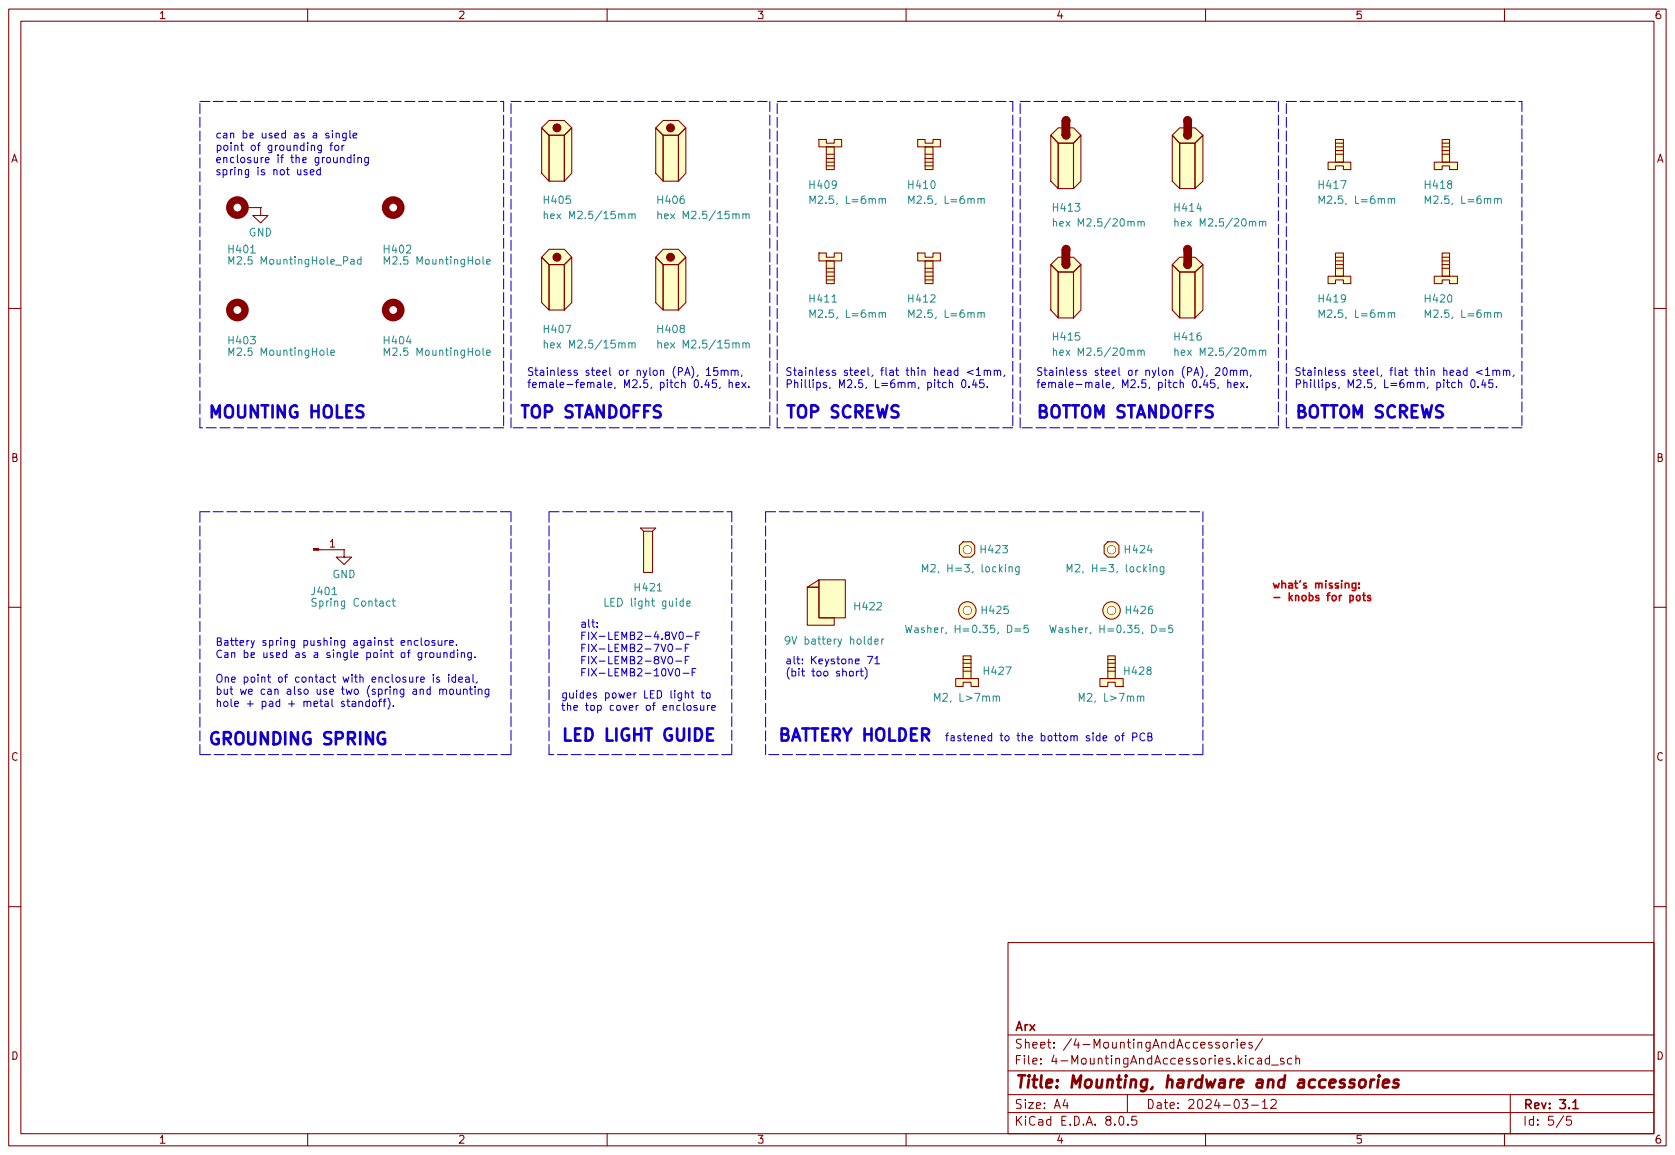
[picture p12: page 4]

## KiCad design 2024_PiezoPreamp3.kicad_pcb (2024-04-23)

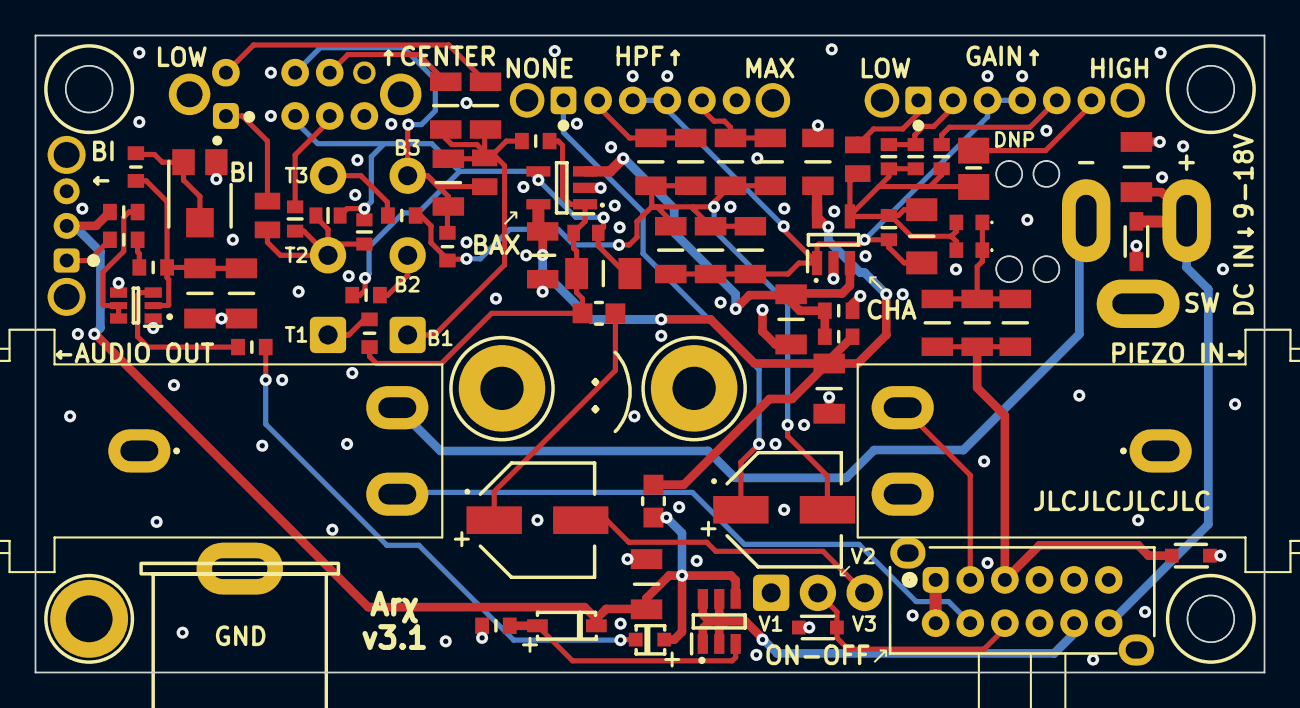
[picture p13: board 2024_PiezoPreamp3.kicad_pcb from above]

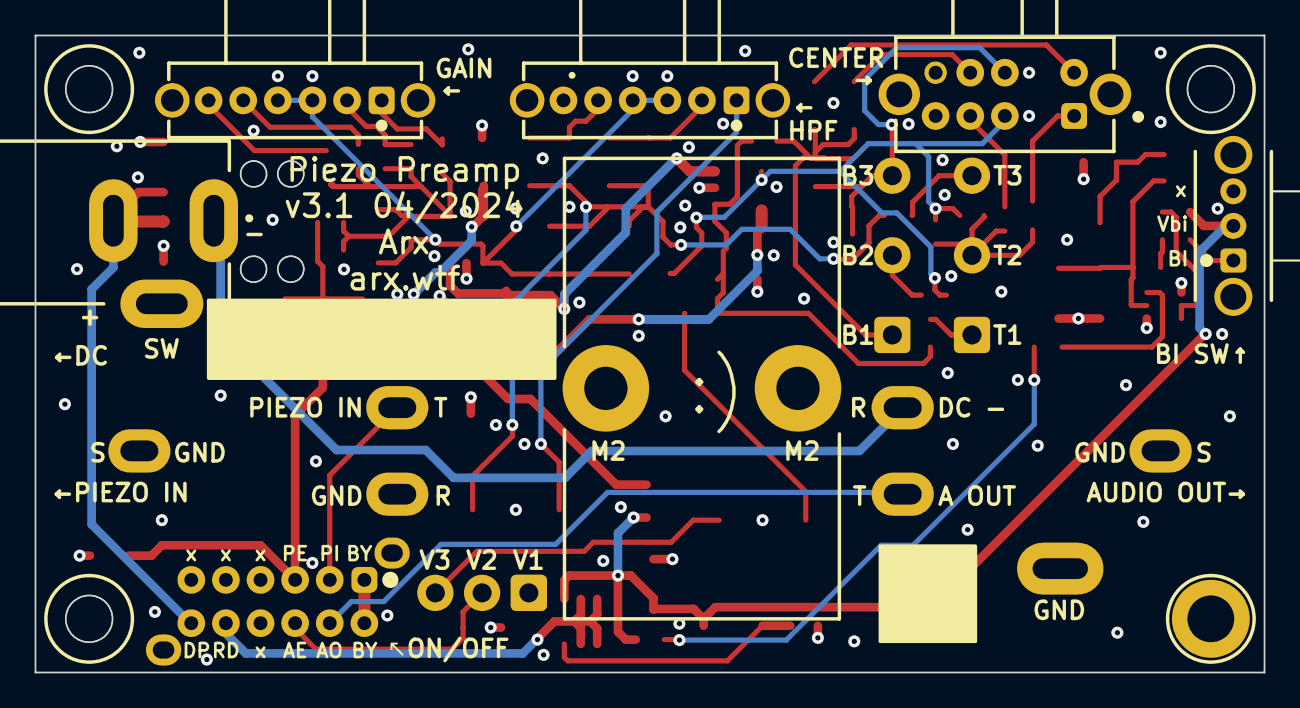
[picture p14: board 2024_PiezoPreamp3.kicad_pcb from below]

Board: 4 copper layers, 71.0 x 36.8 mm, 94 parts (6 on the bottom side), 45 nets.

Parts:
Bass: Bass; pot_R16148-1A-1_FabOnly
Batt1, Batt2, Batt3, Batt4: FreeHole_1.5mm
C101, C102, C103: 220n; GRM31C5C1H224JE02L
C104: 100p; cap_CL10C101JB8NNNC
C105: 100u 50V; EEEFTH101XAP
C201, C202, C203, C204, C301, C302: 22u; cap_CL31A226KAHNNNE
C205, C206: 100n; GRM31C5C1H104JA01L
Cb101, Cb104: 68n; GRM31C5C1H683JA01L
Cb102: 22n; GRM21B5C1H223JA01L
Cb103: 100n; GRM31C5C1H104JA01L
Cf101: 1n; GRM1885C1H102JA01D
Cf102: 22n; GRM21B5C1H223JA01L
Cf103, Cf104, Cf105: 4n7; GRM1885C1H472JA01D
Cf106: 1n; cap_SMD_DNP
Chp101, Chp108: 68n; GRM31C5C1H683JA01L
Chp102, Chp103, Chp105, Chp106: 220n; GRM31C5C1H224JE02L
Chp104: 100u 50V; EEEFTH101XAP
Chp107: 100n; GRM31C5C1H104JA01L
Ct101, Ct102, Ct104: 4n7; GRM1885C1H472JA01D
Ct103: 22n; GRM21B5C1H223JA01L
D101, D102: 12V 1pF; CDSOD323-T12LC
D201: 20V 15pF; D20V0L1B2WS-7
D202: DDZ12B-7
D301: Red 100mcd/120°/2mA; APT1608LSECK_J3-PRV
H101: Bass 1; FreePad_1.1mm_2.1mm_rect
H102: Bass 2; FreePad_1.1mm_2.1mm
H103: Bass 3; FreePad_1.1mm_2.1mm
H104: Treble 1; FreePad_1.1mm_2.1mm_rect
H105: Treble 2; FreePad_1.1mm_2.1mm
H106: Treble 3; FreePad_1.1mm_2.1mm
H107: Volume 1; FreePad_1.1mm_2.1mm_rect
H108: Volume 2; FreePad_1.1mm_2.1mm
H109: Volume 3; FreePad_1.1mm_2.1mm
H401: M2.5 MountingHole_Pad; MountingHole_2.7mm_M2.5_ISO14580_Pad
H402, H403, H404: M2.5 MountingHole; MountingHole_2.7mm_M2.5_ISO14580
H422: 9V battery holder; KEYSTONE-71
J101, J102: 6.3mm stereo; CUI_SJ-63053A
J201: DC IN 5.5/2.1mm; 694106301002
J401: Spring Contact; KEYSTONE-5201
R101, R102: 150R; ERA-3AEB151V
R103, R303: 3k9; RT0603FRE073K9L
R104: 10M; MCA1206MD1005BP100
R105, R202: 100R; ERA-6AEB101V
R201, R305: 10k; RT0603BRD0710KL
R203, R204, R301, R302, R304: 47k; RT0603FRD0747KL
RV301: trim B10k; trimpot_TC33X-2-103E
Rb101, Rb102: 3k9; RT0603FRE073K9L
Rf101: 10M; MCA1206MD1005BP100
Rt101, Rt102: 2k2; RT0603DRD072K2L
S101, S102: SK14D01G6; sw_SK14D01G6
S103: 0S203011MA2QP1; sw_0S203011MA2QP1
S201: EG4208A
S301: OS102011MA1QN1
Treble: Treble; pot_R16148-1A-1_FabOnly
U101, U102: OPA145; OPA145IDBVR
U201: ZXMP3A17E6TA
U301: BC847BS,115; bjt_BC847BS_115
Volume: Volume; pot_R16148-1A-1_FabOnly

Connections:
/1-ChargeAmpAndEQ/BASS_1: Cb101.2, Cb102.1, Cb103.2, Cb104.2, H101.1, Rb102.1
/1-ChargeAmpAndEQ/BASS_2: H102.1, R103.1
/1-ChargeAmpAndEQ/BASS_3: Cb101.1, Cb102.2, H103.1, Rb101.2, S103.6 (1_C)
/1-ChargeAmpAndEQ/BAX_A_INV: C104.1, Ct101.1, Ct102.1, R103.2, R104.2, S103.2 (2_C), U102.4 (-)
/1-ChargeAmpAndEQ/BAX_A_OUT: C104.2, R104.1, R105.2, Rb102.2, Rt102.2, U102.1
/1-ChargeAmpAndEQ/BAX_IN: Chp101.2, Chp102.2, Chp103.2, Chp104.2, Chp105.1, Chp106.1, Chp107.2, Chp108.2, Rb101.1, Rt101.1
/1-ChargeAmpAndEQ/CH_A_INV: Cf101.1, Cf102.1, Cf103.1, Cf104.1, Cf105.1, Cf106.1, R101.2, R102.2, Rf101.1, U101.4 (-)
/1-ChargeAmpAndEQ/CH_A_OUT: Cf101.2, Chp101.1, Chp102.1, Chp103.1, Rf101.2, S101.3 (C1), S101.4 (C2), S102.3 (C1), S102.4 (C2), U101.1
/1-ChargeAmpAndEQ/CIN_RIN: C101.2, C102.2, C103.2, R101.1, R102.1
/1-ChargeAmpAndEQ/C_SW_1: Ct103.2, S103.1 (2_1)
/1-ChargeAmpAndEQ/C_SW_2: Ct104.2, S103.3 (2_2)
/1-ChargeAmpAndEQ/C_SW_5: Cb103.1, S103.5 (1_1)
/1-ChargeAmpAndEQ/C_SW_7: Cb104.1, S103.7 (1_2)
/1-ChargeAmpAndEQ/G_SW_1: Cf102.2, S101.1
/1-ChargeAmpAndEQ/G_SW_2: Cf103.2, Cf104.2, S101.2
/1-ChargeAmpAndEQ/G_SW_5: Cf105.2, S101.5 (3)
/1-ChargeAmpAndEQ/G_SW_6: Cf106.2, S101.6 (4)
/1-ChargeAmpAndEQ/HPF_SW_1: Chp104.1, S102.1
/1-ChargeAmpAndEQ/HPF_SW_2: Chp105.2, Chp106.2, S102.2
/1-ChargeAmpAndEQ/HPF_SW_3: Chp107.1, Chp108.1, S102.5 (3)
/1-ChargeAmpAndEQ/ROUT_COUT: C105.1, R105.1
/1-ChargeAmpAndEQ/TREB_1: H104.1, Rt102.1
/1-ChargeAmpAndEQ/TREB_2: Ct101.2, Ct102.2, Ct103.1, Ct104.1, H105.1
/1-ChargeAmpAndEQ/TREB_3: H106.1, Rt101.2
/1-ChargeAmpAndEQ/VOL_3: C105.2, H109.1
/2-Power/BYPASS: S201.1, S201.7
/2-Power/DC_IN_POS: C201.2, D201.2 (A2), J201.2 (SLEEVE), S201.12
/2-Power/RP_DRAIN: S201.11, U201.1, U201.2, U201.5, U201.6
/2-Power/RP_GATE: D202.2 (A), R201.1, U201.3
/3-BatteryIndicator/BI_B1: C301.2, C302.2, R302.2, R303.1, U301.2 (B1)
/3-BatteryIndicator/BI_C1_B2: R304.2, U301.5 (B2), U301.6 (C1)
/3-BatteryIndicator/BI_C2: R305.2, U301.3 (C2)
/3-BatteryIndicator/BI_R: R301.2, R302.1
/3-BatteryIndicator/BI_SW: R301.1, S301.1
/3-BatteryIndicator/LED_K: D301.1 (K), R305.1
/3-BatteryIndicator/TRIM_BI_3: R303.2, RV301.2, RV301.3
AUDIO_ESD: D102.2 (A2), H108.1, S201.9
AUDIO_OUT: J102.2, S201.8
DC_IN_NEG: J102.3, J201.1 (CENTER)
GND: C201.1, C202.1, C203.1, C204.1, C205.1, C206.1, C301.1, C302.1, D101.1 (A1), D102.1 (A1), D201.1 (A1), H107.1, H401.1, J101.1, J101.3, J102.1, J401.1, R201.2, R204.2, RV301.1, U101.2 (V-), U102.2 (V-), U301.1 (E1), U301.4 (E2)
PIEZO_ESD: C101.1, C102.1, C103.1, D101.2 (A2), S201.3
PIEZO_IN: J101.2, S201.2
VS: C203.2, C205.2, C206.2, R202.1, R203.1, U101.5 (V+), U102.5 (V+)
Vbi: C202.2, D202.1 (K), D301.2 (A), R202.2, R304.1, S301.2, U201.4
Vbias: C204.2, R203.2, R204.1, U101.3 (+), U102.3 (+)

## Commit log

2023-12-07 adding main project files and symbol/footprint/3d model library
    [1-ChargeAmpAndEQ.kicad_sch, 2-Power.kicad_sch, 2023_PiezoPreamp.kicad_pcb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]
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2023-12-07 resolving all violations of stitching vias
    [2023_PiezoPreamp.kicad_pcb]
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2023-12-07 final touches to board and schematic before manufacture / assembly
    [2023_PiezoPreamp.kicad_pcb, 4-MountingAndAccessories.kicad_sch]
2023-12-07 generating production files: gerbers, drill files, positions, BOM for assembly
    [2023_PiezoPreamp-B_Cu.gbl, 2023_PiezoPreamp-B_Mask.gbs, 2023_PiezoPreamp-B_Paste.gbp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]
2023-12-08 bumping revision number to v2.1
    [1-ChargeAmpAndEQ.kicad_sch, 2-Power.kicad_sch, 3-BatteryIndicator.kicad_sch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]
2023-12-08 fixing some of 0805 and 1206 land patterns so that they have enough soldering area (after JLC feedback)
    [2023_PiezoPreamp.kicad_pcb, 2023_PiezoPreamp.kicad_sch]
2023-12-08 fixing footprints - making pin 1 dots more prominent, adding + signs to caps and diodes
2023-12-08 PCB: few minor fixes, vias etc
    [2023_PiezoPreamp.kicad_pcb]
2023-12-08 v2.1: new production gerbers
    [2023_PiezoPreamp-B_Cu.gbl, 2023_PiezoPreamp-B_Mask.gbs, 2023_PiezoPreamp-B_Paste.gbp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]
2023-12-08 v2.1: new production assembly files
    [bom.csv, designators.csv, positions.csv]
2023-12-08 new production gerbers (still v2.1, correcting silkscreen mistake)
    [2023_PiezoPreamp-B_Cu.gbl, 2023_PiezoPreamp-B_Mask.gbs, 2023_PiezoPreamp-B_Paste.gbp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]
2023-12-08 updating the project and board (silkscreen mistake, was v2.0 instead of v2.1)
    [2023_PiezoPreamp.kicad_pcb]
2023-12-27 v2.2: correcting pins of audio jacks - T and R were swapped. Fixing in schematic and PCB
    [1-ChargeAmpAndEQ.kicad_sch, 2-Power.kicad_sch, 2023_PiezoPreamp.kicad_pcb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]
2023-12-27 v2.2: new production files (gerbers, drills, positions, bom)
    [2023_PiezoPreamp-B_Cu.gbl, 2023_PiezoPreamp-B_Mask.gbs, 2023_PiezoPreamp-B_Paste.gbp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]
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2024-01-17 v2.3: adjusting board dimensions to better fit Teko 1/A.1 enclosure. Increasing pad sizes for opamps and 10M resistors to make hand soldering easier.
    [1-ChargeAmpAndEQ.kicad_sch, 2-Power.kicad_sch, 2023_PiezoPreamp.kicad_pcb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]
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2024-02-11 improving the schematic - v3.0. Very crude draft of board layout with battery holder underneath the PCB
    [1-ChargeAmpAndEQ.kicad_sch, 2-Power.kicad_sch, 2023_PiezoPreamp.kicad_pcb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]
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2024-02-12 saving in Kicad8 for the first time - some underlying formats changed
    [1-ChargeAmpAndEQ.kicad_sch, 2-Power.kicad_sch, 2023_PiezoPreamp.kicad_sch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]
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2024-02-15 schematics: heavy BOM optimization, many small changes, filling missing fields, improving symbols and everything
    [1-ChargeAmpAndEQ.kicad_sch, 2-Power.kicad_sch, 2023_PiezoPreamp.kicad_sch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]
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2024-02-15 aligning schematics to grid, swapping switches as they are on the bottom side now; rough placement of BI section on board
    [1-ChargeAmpAndEQ.kicad_sch, 2-Power.kicad_sch, 2023_PiezoPreamp.kicad_pcb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]
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2024-02-18 schematics: replacing the switches, rewiring, improving center switch positions, removing 6n8 cap
    [1-ChargeAmpAndEQ.kicad_sch, 2-Power.kicad_sch, 3-BatteryIndicator.kicad_sch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]
2024-02-18 PCB: updating all component footprints from schematics; starting some basic placement again
    [2023_PiezoPreamp.kicad_pcb]
2024-02-20 schematic: renaming low-pass filter to high-pass filter as it was named incorrectly lol
    [1-ChargeAmpAndEQ.kicad_sch, 2-Power.kicad_sch]
2024-02-20 updating the board and remaining low-pass references in schematic
    [1-ChargeAmpAndEQ.kicad_sch, 2023_PiezoPreamp.kicad_pcb]
2024-02-20 Schematic: replacing SP3T HPF switch with SP4T again, adding the new HPF cutoff position, moving libraries around. Choosing different 150R resistor because of availability
    [1-ChargeAmpAndEQ.kicad_sch, 2-Power.kicad_sch, 2023_PiezoPreamp.kicad_sch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]
2024-02-22 Update README.md - correcting filter name
2024-02-22 fixing missing DC jack; continued working on the board layout
    [2-Power.kicad_sch, 2023_PiezoPreamp.kicad_pcb, 3-BatteryIndicator.kicad_sch]
2024-02-22 correcting the filter name to HPF in schematic, board and in exported schematics
    [1-ChargeAmpAndEQ.kicad_sch, 2-Power.kicad_sch, 2023_PiezoPreamp.kicad_pcb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]
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2024-03-05 schematic, PCB: defining net classes, assigning different color for Power, getting rid of 0.3493 trace width which was kinda silly anyway
    [2024_PiezoPreamp3.kicad_pcb]
2024-03-05 PCB: changing all via sizes to 0.3/0.7 as bigger don't make any sense
    [2024_PiezoPreamp3.kicad_pcb]
2024-03-05 PCB: making all power traces 0.4mm wide as 0.5mm is excessive
    [2024_PiezoPreamp3.kicad_pcb]
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2024-03-07 Schematic, PCB: moving DC ESD protection in front of the switch. Using one 22uF bulk decoupling cap where DC enters the board instead of two 10uF near opamps. Using 22uF instead of 10uF in opamp bias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
    [1-ChargeAmpAndEQ.kicad_sch, 2-Power.kicad_sch, 2024_PiezoPreamp3.kicad_pcb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]
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2024-03-07 PCB: changing power traces to 0.5mm width again. I have enough space and the inductance is lower
    [2024_PiezoPreamp3.kicad_pcb]
2024-03-07 PCB: enlarging all the pads that will be manually soldered
    [2024_PiezoPreamp3.kicad_pcb]
2024-03-08 Using larger footprint for DNP feedback cap; small improvements
    [1-ChargeAmpAndEQ.kicad_sch, 2024_PiezoPreamp3.kicad_pcb]
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2024-03-10 schematic: optimizing few BOM items (for less costly alternatives), few updates
    [1-ChargeAmpAndEQ.kicad_sch, 2-Power.kicad_sch, 2024_PiezoPreamp3.kicad_sch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]
2024-03-10 PCB: finishing layout & routing, improving silkscreen everywhere, checking rules
    [2024_PiezoPreamp3.kicad_pcb]
2024-03-11 PCB: moving tracks & vias so that the signals don't cross holes in gnd planes cause by signal vias
    [2024_PiezoPreamp3.kicad_pcb]
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2024-03-11 PCB: improving track aesthetics, some vias, zone corners. Setting plot outputs closer to JLC recommendation
    [2024_PiezoPreamp3.kicad_pcb]
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2024-03-11 PCB: locking all footprints, text and graphics. Excluding THT from BOM for fabrication purposes
    [2024_PiezoPreamp3.kicad_pcb]
2024-03-11 PCB: adding free holes for battery jack cables. Moving things around a bit
    [2024_PiezoPreamp3.kicad_pcb]
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2024-04-08 library: marking THT components as 'excluded from position files' as otherwise kicad would bug me with 'doesnt match library' warnings forever
2024-04-08 PCB: v3.1 - small adjustments to DC IN jack footprint, DC ESD footprint, moving things a little, increasing S/N field size, etc
    [2024_PiezoPreamp3.kicad_pcb]
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2024-04-23 updating README, render, small things in schematics and pcb
    [2-Power.kicad_sch, 2024_PiezoPreamp3.kicad_pcb]
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2025-01-11 Schematics: improving a few comments and their positions
    [1-ChargeAmpAndEQ.kicad_sch, 2-Power.kicad_sch, 2024_PiezoPreamp3.kicad_sch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]
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
